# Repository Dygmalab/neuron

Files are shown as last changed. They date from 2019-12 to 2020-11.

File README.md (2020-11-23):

# neuron
Neuron PCB of the Dygma Raise keyboard

Licensed under CERN-OHL and distributed as is without any additional warranty or documentation.

#### Usefull links
[Neuron](https://github.com/Dygmalab/neuron)

[Right side schematics](https://github.com/Dygmalab/raise-right-asym)

[Right bottom schematics](https://github.com/Dygmalab/right-lp)

[Left side schematics](https://github.com/Dygmalab/raise-left)

[Left bottom schematics](https://github.com/Dygmalab/left-lp)

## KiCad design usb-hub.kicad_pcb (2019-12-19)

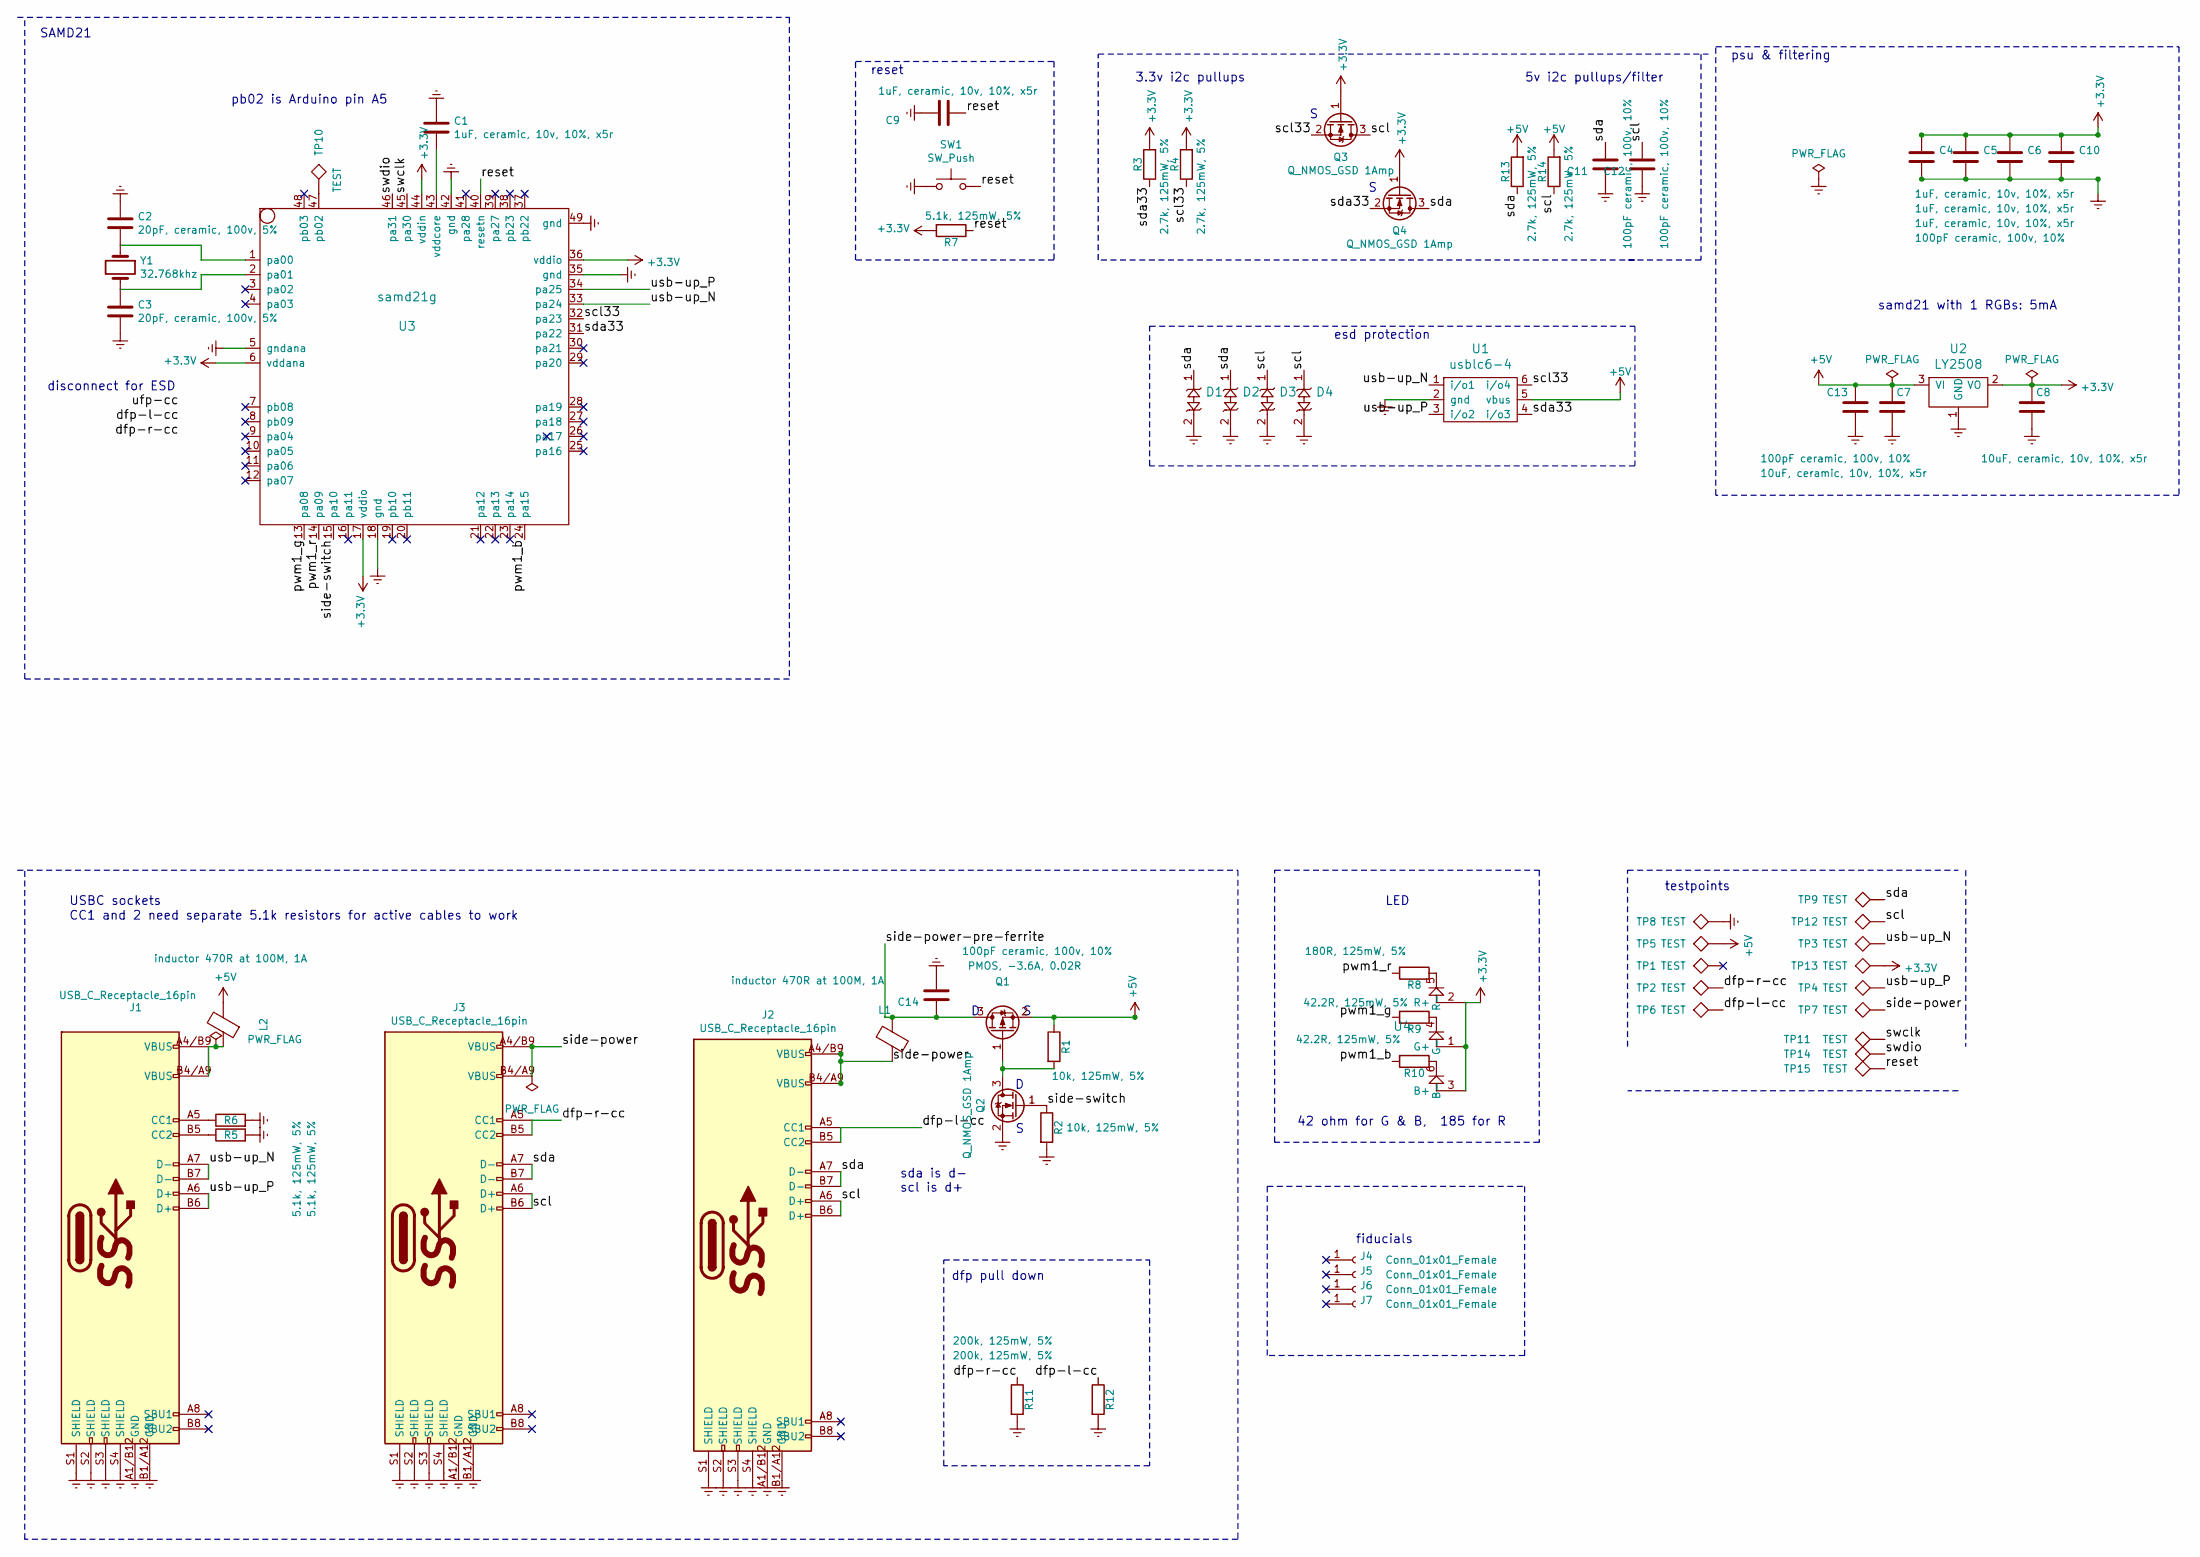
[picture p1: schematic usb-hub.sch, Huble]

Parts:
C1, C4, C5, C6: 1uF, ceramic, 10v, 10%, x5r; C_0603; farnell # 1865556
C2, C3: 20pF, ceramic, 100v, 5%; C_0603; farnell # 1865475
C7, C8: 10uF, ceramic, 10v, 10%, x5r; C_0603; farnell # 1288201
C9: 1uF, ceramic, 10v, 10%, x5r; C_0603; farnell # 2821263
C10, C11, C12, C13, C14: 100pF ceramic, 100v, 10%; C_0603; farnell # 2821263
D1, D2, D3, D4: ESD-diode; sod882
J1, J2, J3: USB_C_Receptacle_16pin; usb-c-16smt
J4, J5, J6, J7: Conn_01x01_Female; Fiducial_0.5mm_Dia_1mm_Outer
L1, L2: inductor 470R at 100M, 1A; R_0603; farnell # 1515745
Q1: PMOS, -3.6A, 0.02R; SOT-23; farnell # 2061419
Q2, Q3, Q4: Q_NMOS_GSD 1Amp; SOT-323_SC-70; farnell # 2061403
R1, R2: 10k, 125mW, 5%; R_0603; farnell # 2447230
R3, R4, R13, R14: 2.7k, 125mW, 5%; R_0603; farnell # 2447324
R5, R6: 5.1k, 125mW, 5%; R_0603; farnell # 2447404
R7: 5.1k, 125mW, 5%; R_0603; farnell # 2447230
R8: 180R, 125mW, 5%; R_0603; farnell # 2447267
R9, R10: 42.2R, 125mW, 5%; R_0603; farnell # 2694864
R11, R12: 200k, 125mW, 5%; R_0603; farnell # 2447291
SW1: SW_Push; reset-button
TP1, TP2, TP3, TP4, TP5, TP6, TP7, TP8, TP9, TP10, TP11, TP12, TP13, TP14, TP15: TEST; testpoint
U1: usblc6-4; SOT-23-6; farnell # 1295311
U2: LY2508; SOT-23; farnell # 2218573
U3: samd21g; QFN-48-1EP_7x7mm_Pitch0.5mm; farnell # 2409249
U4: 4 pin RGB led, com anode; 3528-4p
Y1: 32.768khz; Crystal_SMD_3215-2pin_3.2x1.5mm; farnell # 2449501

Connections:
+3V3: C4.1, C5.1, C6.1, C8.1, C10.1, Q3.1 (G), Q4.1 (G), R3.2, R4.2, R7.2, TP13.1, U2.2 (VO), U3.6 (vddana), U3.17 (vddio), U3.36 (vddio), U3.44 (vddin), U4.1 (G+), U4.2 (R+), U4.3 (B+)
+5V: C7.1, C13.1, L2.2, Q1.2 (S), R1.1, R13.2, R14.2, TP5.1, U1.5 (vbus), U2.3 (VI)
/dfp-l-cc: J2.A5 (CC1), J2.B5 (CC2), R12.1, TP6.1
/dfp-r-cc: J3.A5 (CC1), J3.B5 (CC2), R11.1, TP2.1
/pwm1_b: R10.2, U3.24 (pa15)
/pwm1_g: R9.2, U3.13 (pa08)
/pwm1_r: R8.2, U3.14 (pa09)
/reset: C9.1, R7.1, SW1.2, TP15.1, U3.40 (resetn)
/scl: C12.2, D3.1, D4.1, J2.A6 (D+), J2.B6 (D+), J3.A6 (D+), J3.B6 (D+), Q3.3 (D), R14.1, TP12.1
/scl33: Q3.2 (S), R4.1, U1.6 (i/o4), U3.32 (pa23)
/sda: C11.2, D1.1, D2.1, J2.A7 (D-), J2.B7 (D-), J3.A7 (D-), J3.B7 (D-), Q4.3 (D), R13.1, TP9.1
/sda33: Q4.2 (S), R3.1, U1.4 (i/o3), U3.31 (pa22)
/side-power: J2.A4/B9 (VBUS), J2.B4/A9 (VBUS), J3.A4/B9 (VBUS), J3.B4/A9 (VBUS), L1.2, TP7.1
/side-power-pre-ferrite: C14.1, L1.1, Q1.3 (D)
/side-switch: Q2.1 (G), R2.1, U3.15 (pa10)
/swclk: TP11.1, U3.45 (pa30)
/swdio: TP14.1, U3.46 (pa31)
/usb-up_N: J1.A7 (D-), J1.B7 (D-), TP3.1, U1.1 (i/o1), U3.33 (pa24)
/usb-up_P: J1.A6 (D+), J1.B6 (D+), TP4.1, U1.3 (i/o2), U3.34 (pa25)
Earth: C1.1, C2.1, C3.2, C4.2, C5.2, C6.2, C7.2, C8.2, C9.2, C10.2, C11.1, C12.1, C13.2, C14.2, D1.2, D2.2, D3.2, D4.2, J1.A1/B12 (GND), J1.B1/A12 (GND), J1.S1 (SHIELD), J1.S2 (SHIELD), J1.S3 (SHIELD), J1.S4 (SHIELD), J2.A1/B12 (GND), J2.B1/A12 (GND), J2.S1 (SHIELD), J2.S2 (SHIELD), J2.S3 (SHIELD), J2.S4 (SHIELD), J3.A1/B12 (GND), J3.B1/A12 (GND), J3.S1 (SHIELD), J3.S2 (SHIELD), J3.S3 (SHIELD), J3.S4 (SHIELD), Q2.2 (S), R2.2, R5.2, R6.2, R11.2, R12.2, SW1.1, TP8.1, U1.2 (gnd), U2.1 (GND), U3.5 (gndana), U3.18 (gnd), U3.35 (gnd), U3.42 (gnd), U3.49 (gnd)
unnamed: C1.2, U3.43 (vddcore)
unnamed: C2.2, U3.1 (pa00), Y1.1
unnamed: C3.1, U3.2 (pa01), Y1.2
unnamed: J1.A4/B9 (VBUS), J1.B4/A9 (VBUS), L2.1
unnamed: J1.A5 (CC1), R6.1
unnamed: J1.B5 (CC2), R5.1
unnamed: Q1.1 (G), Q2.3 (D), R1.2
unnamed: R8.1, U4.5 (R-)
unnamed: R9.1, U4.4 (G-)
unnamed: R10.1, U4.6 (B-)
unnamed: TP10.1, U3.47 (pb02)

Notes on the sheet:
samd21 with 1 RGBs: 5mA
testpoints
esd protection
42 ohm for G & B, 185 for R
sda is d- scl is d+
dfp pull down
fiducials
3.3v i2c pullups
pb02 is Arduino pin A5
5v i2c pullups/filter
psu & filtering
reset
USBC sockets
LED
SAMD21
disconnect for ESD
CC1 and 2 need separate 5.1k resistors for active cables to work

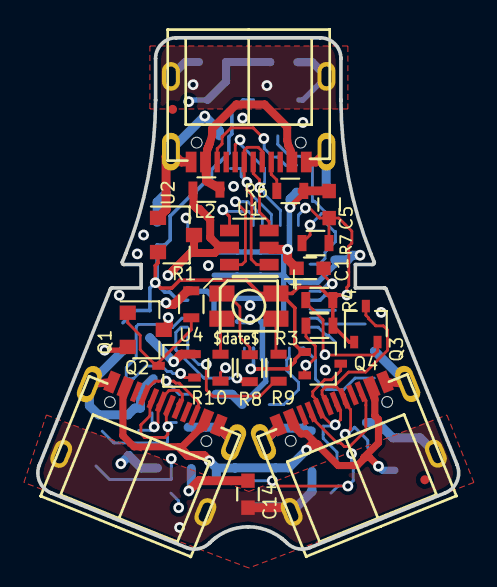
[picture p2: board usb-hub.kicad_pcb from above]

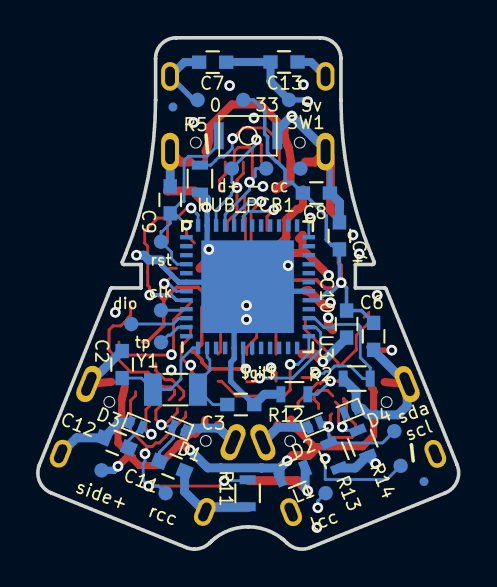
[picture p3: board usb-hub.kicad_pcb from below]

Board: 4 copper layers, 23.4 x 28.4 mm, 66 parts (42 on the bottom side), 31 nets.

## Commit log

2018-01-19 fixed usb routing, added reset, bigger board, dygma logo
    [huble.sch, usb-hub.kicad_pcb, usb-hub.sch]
2018-01-25 switched to smt usbc plugs and added power switching for both sockets
    [huble.sch, usb-hub.kicad_pcb, usb-hub.sch]
2018-01-25 fixed a track bug
    [usb-hub.kicad_pcb]
2018-01-26 moved design files up 1 dir
    [huble.sch, usb-hub.kicad_pcb, usb-hub.sch]
2018-01-26 fixed missing cap on schematic, and fixed up post move netlist
    [huble.sch, usb-hub.kicad_pcb, usb-hub.sch]
2018-02-09 remove wrong farnell codes, use same 47u tant cap in both places
    [huble.sch, usb-hub.sch]
2018-03-05 updated for BOM
    [huble.sch]
2018-03-05 fixed wrong i2c pinout text
    [usb-hub.kicad_pcb]
2018-03-09 mid layout arm
    [usb-hub.kicad_pcb]
2018-03-13 v2.1 ready for fab
    [huble.sch, usb-hub.kicad_pcb, usb-hub.sch]
2018-03-20 bom updated for 0603 parts and farnell order
    [huble.sch, usb-hub.sch]
2018-03-23 fixed vddcore error
    [huble.sch, usb-hub.sch]
2018-04-02 v2.2 - new hub chip, regulator and USB A
    [huble.sch, usb-hub.kicad_pcb, usb-hub.sch]
2018-04-02 fixed ref position
    [usb-hub.kicad_pcb]
2018-04-09 farnell numberse
    [huble.sch, usb-hub.sch]
2018-04-09 added dimensions on the drawing layer
    [usb-hub.kicad_pcb]
2018-04-13 fix some BOM values
    [huble.sch]
2018-04-17 changed micro, working on port switches
    [huble.sch, usb-hub.sch]
2018-04-18 differential routing, test pads
    [huble.sch, usb-hub.kicad_pcb, usb-hub.sch]
2018-04-18 4 esd diodes
    [huble.sch, usb-hub.kicad_pcb]
2018-04-19 v2.3 sent to fab
    [huble.sch, usb-hub.kicad_pcb, usb-hub.sch]
2018-04-23 updated part numbers and specs
    [huble.sch, usb-hub.sch]
2018-05-21 remove wrong farnell partnum
    [usb-hub.sch]
2018-05-21 footprints in submodule
    [huble.sch, usb-hub.kicad_pcb, usb-hub.sch]
2018-05-25 removed hub and new board layout
    [huble.sch, usb-hub.kicad_pcb, usb-hub.sch]
2018-05-30 wip neuron layout
    [usb-hub.kicad_pcb, usb-hub.sch]
2018-06-27 added holes
    [usb-hub.kicad_pcb, usb-hub.sch]
2018-06-27 better ground pours
    [usb-hub.kicad_pcb]
2018-06-29 ansi/iso bom
    [usb-hub.kicad_pcb, usb-hub.sch]
2018-07-03 pcb colours
2018-07-16 hide many values
    [usb-hub.kicad_pcb]
2018-07-25 fixes for gp
    [usb-hub.kicad_pcb, usb-hub.sch]
2018-08-06 led updated to show fp on fab layer
    [usb-hub.kicad_pcb]
2018-08-28 moved sockets in by 1.25mm
    [usb-hub.kicad_pcb, usb-hub.sch]
2018-09-03 moving sockets
    [usb-hub.kicad_pcb]
2018-09-03 replaced programming header with test pads
    [usb-hub.kicad_pcb, usb-hub.sch]
2018-09-04 keep outs ok, silk screen done
    [usb-hub.kicad_pcb]
2018-09-05 dnp esd and add inductor name to component value
    [usb-hub.sch]
2018-09-05 fixed broken testpoint positions
    [usb-hub.kicad_pcb]
2018-09-06 moved regulator out of keep out zone
    [usb-hub.kicad_pcb]
2018-09-06 moved test points further away from board
    [usb-hub.kicad_pcb]
2018-09-13 final checks
    [usb-hub.kicad_pcb]
2018-09-20 fix mixup of swclk and swdio pads in schematic, updated changed inductor text to board file
    [usb-hub.kicad_pcb, usb-hub.sch]
2018-10-12 add datasheet to esd protector
    [usb-hub.sch]
2018-11-15 100pf caps for ESD and I2C level shifter
    [usb-hub.kicad_pcb, usb-hub.sch]
2018-11-15 split git version into git and date
    [usb-hub.kicad_pcb]
2018-11-28 changed visible layers, removed drawings
    [usb-hub.kicad_pcb]
2018-12-13 slight change to USBC routing and changed USBC connectors mask around locator pins
    [usb-hub.kicad_pcb]
2018-12-14 increased outline of edge cuts
    [usb-hub.kicad_pcb]
2018-12-17 added big pads for USBC
    [usb-hub.kicad_pcb]
2018-12-21 change usbC to smt type
    [usb-hub.kicad_pcb]
2018-12-21 change usb ESD protector to be placed
    [usb-hub.sch]
2018-12-21 change fiducial to SMD type
    [usb-hub.kicad_pcb]
2019-01-16 improve clarity of polarity of u5
    [usb-hub.kicad_pcb]
2019-01-22 esd fixes: remove adc connections, protect usb +-, move esd protection
    [usb-hub.kicad_pcb, usb-hub.sch]
2019-01-22 thicker line for pin 1 of sot6
2019-02-07 remove tiny translator and go back to 2 mosfets, also fix farnell number on 2.7k R
    [usb-hub.sch]
2019-02-20 led partnum update
    [usb-hub.sch]
2019-02-27 move cap label
    [usb-hub.sch]
2019-04-02 thickened power traces
    [usb-hub.kicad_pcb]
2019-04-02 few more gnd vias for the high speed tracks
    [usb-hub.kicad_pcb]
2019-04-03 bom consolidation
    [usb-hub.sch]
2019-04-24 fixed reset filter
    [usb-hub.kicad_pcb, usb-hub.sch]
2019-05-27 ESD fixes recommmended by ASIM. Also better caps distribution
    [usb-hub.kicad_pcb, usb-hub.sch]
2019-06-10 added part number for ASIM ESD diode
    [usb-hub.sch]
2019-06-21 ESD diodes -> SMT
    [usb-hub.kicad_pcb]
2019-07-08 fix missing USB CC resistor
    [usb-hub.kicad_pcb, usb-hub.sch]
2019-07-22 component refs moved
    [usb-hub.sch]
2019-07-22 fixed bsilk for new R
    [usb-hub.kicad_pcb]
2019-12-19 fix led footprint
    [usb-hub.kicad_pcb]
